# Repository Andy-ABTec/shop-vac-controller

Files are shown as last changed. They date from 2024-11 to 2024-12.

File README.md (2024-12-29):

# Shop Vac Controller

An Arduino Nano-based project to provide automatic control for a small workshop vacuum by either sensing tool use, or by a keyfob style remote control.

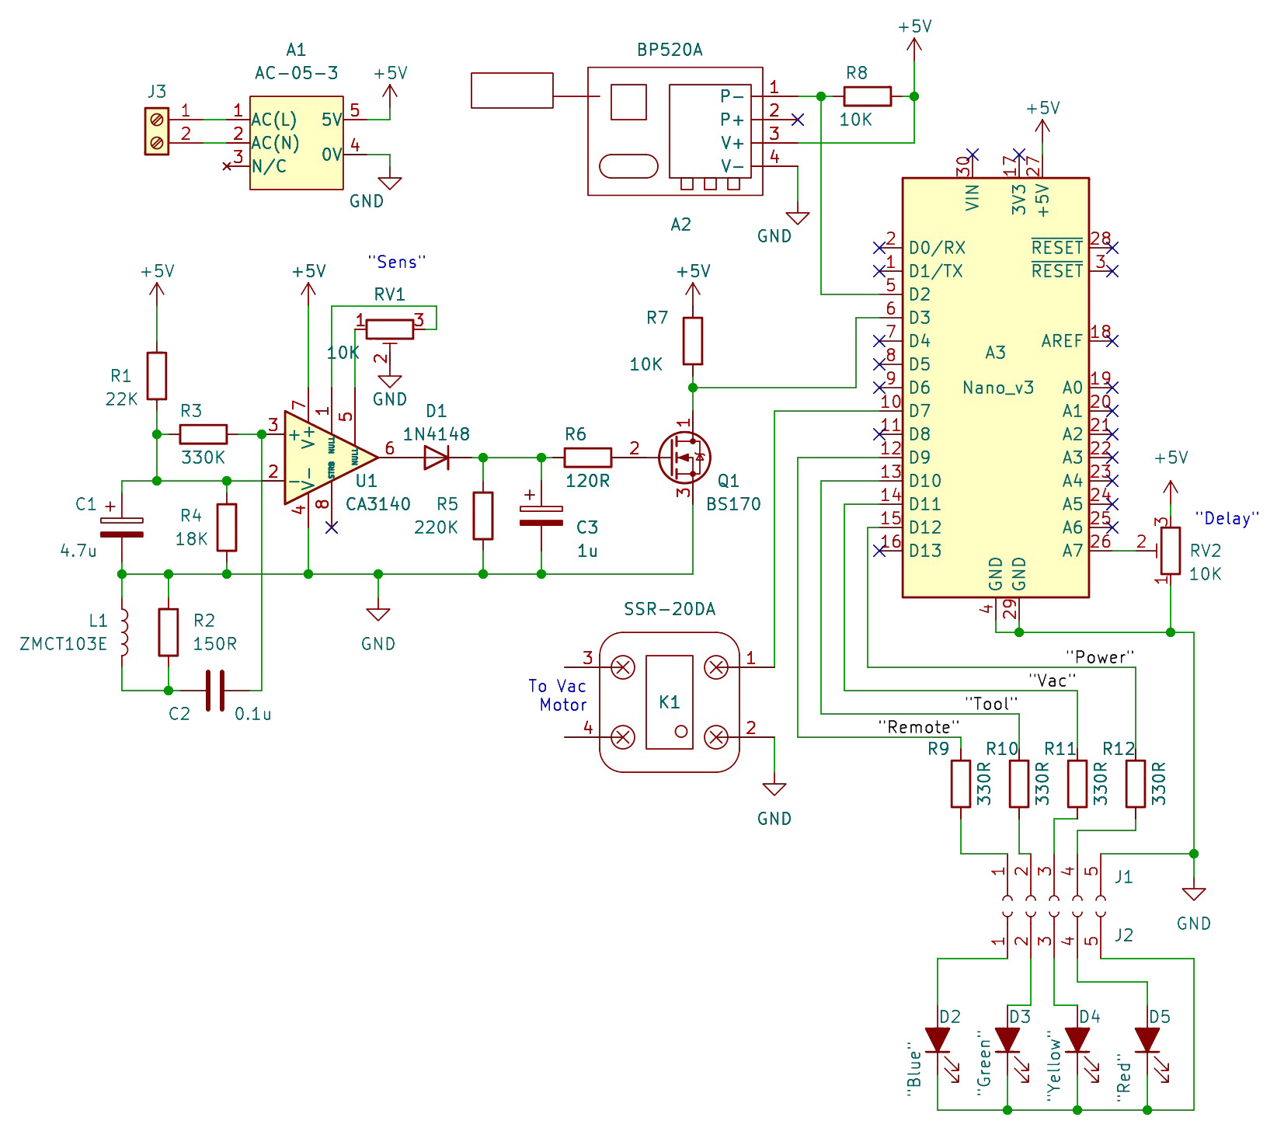
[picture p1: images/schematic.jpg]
schematic


Four LEDs display the status of the controller and its trigger source. It should be noted that the "Vac On" LED flashes if a startup or shutdown delay is in progress.

 Power control for the vacuum is provided by a 20A solid state relay and the remote control by a small keyfob and receiver ( I used a [**fob/receiver** from Amazon](https://www.amazon.co.uk/gp/product/B08SHQ749R/)).

Power-tool on/off sensing is provided by a small circuit by [**0033mer**](https://www.youtube.com/user/0033mer) using a cheap current transformer  I found on [**YouTube**](https://www.youtube.com/watch?v=gvBVxQGS_OU&t=280s).

Both the *sensitivity* of the current sensor and the turn-off delay for the vacuum control relay are adjustable by preset potentiometers.

Whilst the remote has no turn-on delay, the vacuum turns on 3s after the power tool is started (this setting may be adjusted in the Arduino code). This delay helps to reduce the excessive surge current created if both the power tool and the vacuum are turned on together.

The turn-off delay is the same for both the power tool and the remote fob, and can easily be adjusted between 3s and 30s with a preset potentiometer, this allows time for the wood chips and sawdust to be cleared from the vacuum hose.

It should be noted that if the vacuum is initiated by the mains-powered tool turning on, it can only be turned off by stopping the tool, and, in a similar way, if initiated by the remote fob it can only be turned off by the remote fob.

The vacuum power circuit should include a suitable fuse.

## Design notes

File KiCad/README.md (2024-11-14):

# Shop Vac Controller

A small Arduino Nano-based project to provide automatic control for a workshop vacuum by either sensing tool use, or by a keyfob style remote control.
<p align="center"><br>
<br>
<span style="font-size:3;font-style: italic">Circuit Diagram</span></p>Four LEDs display the status of the controller and its trigger source. It should be noted that the "Vac On" LED flashes if a startup or shutdown delay is in progress.

<p align="center"><br>

<br>
<span style="font-size:3;font-style:italic">Power Connections</span></p>

 Power control for the vacuum is provided by a 20A solid state relay and the remote control by a small keyfob and receiver ( I used a [**fob receiver** from Amazon](https://www.amazon.co.uk/gp/product/B08SHQ749R/).

Power-tool on/off sensing is provided by a small circuit by [**0033mer**](https://www.youtube.com/user/0033mer) using a cheap current transformer  I found on [**YouTube**](https://www.youtube.com/watch?v=gvBVxQGS_OU&t=280s).

Both the *sensitivity* of the current sensor and the turn-off delay for the vacuum control relay are adjustable by preset potentiometers.

Whilst the remote has no turn-on delay, the vacuum turns on 3s after the power tool is started (this setting may be adjusted in the Arduino code). This delay helps to reduce the excessive surge current created if both the power tool and the vacuum are turned on together.

The turn-off delay is the same for both the power tool and the remote fob, and can easily be adjusted between 3s and 30s with a preset potentiometer, this allows time for the wood chips and sawdust to be cleared from the vacuum hose.

It should be noted that if the vacuum is initiated by the mains-powered tool turning on it can only be turned off by stopping the tool and, in a similar way, if initiated by the remote fob it can only be turned off by the remote fob.

The vacuum power circuit should include a suitable fuse.

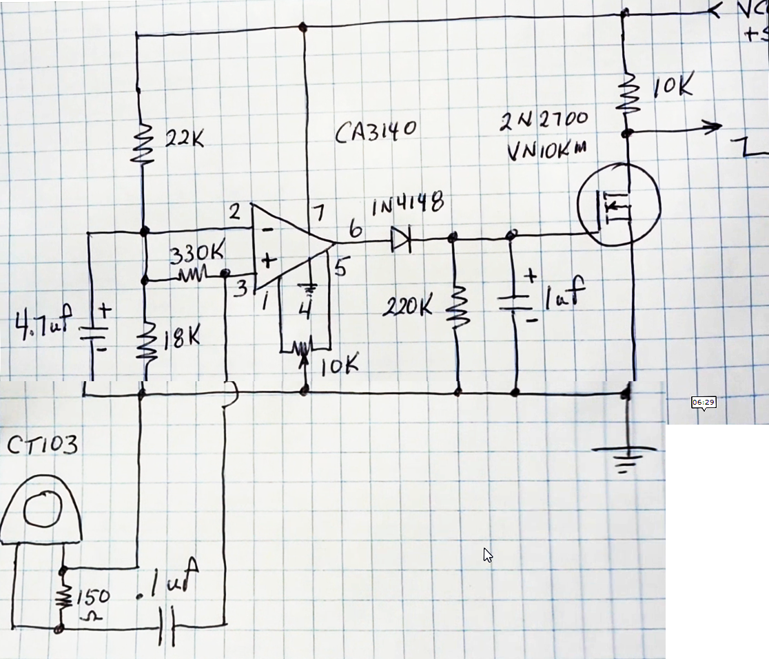
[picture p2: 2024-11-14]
KiCad/AC Current Detection Interface.png

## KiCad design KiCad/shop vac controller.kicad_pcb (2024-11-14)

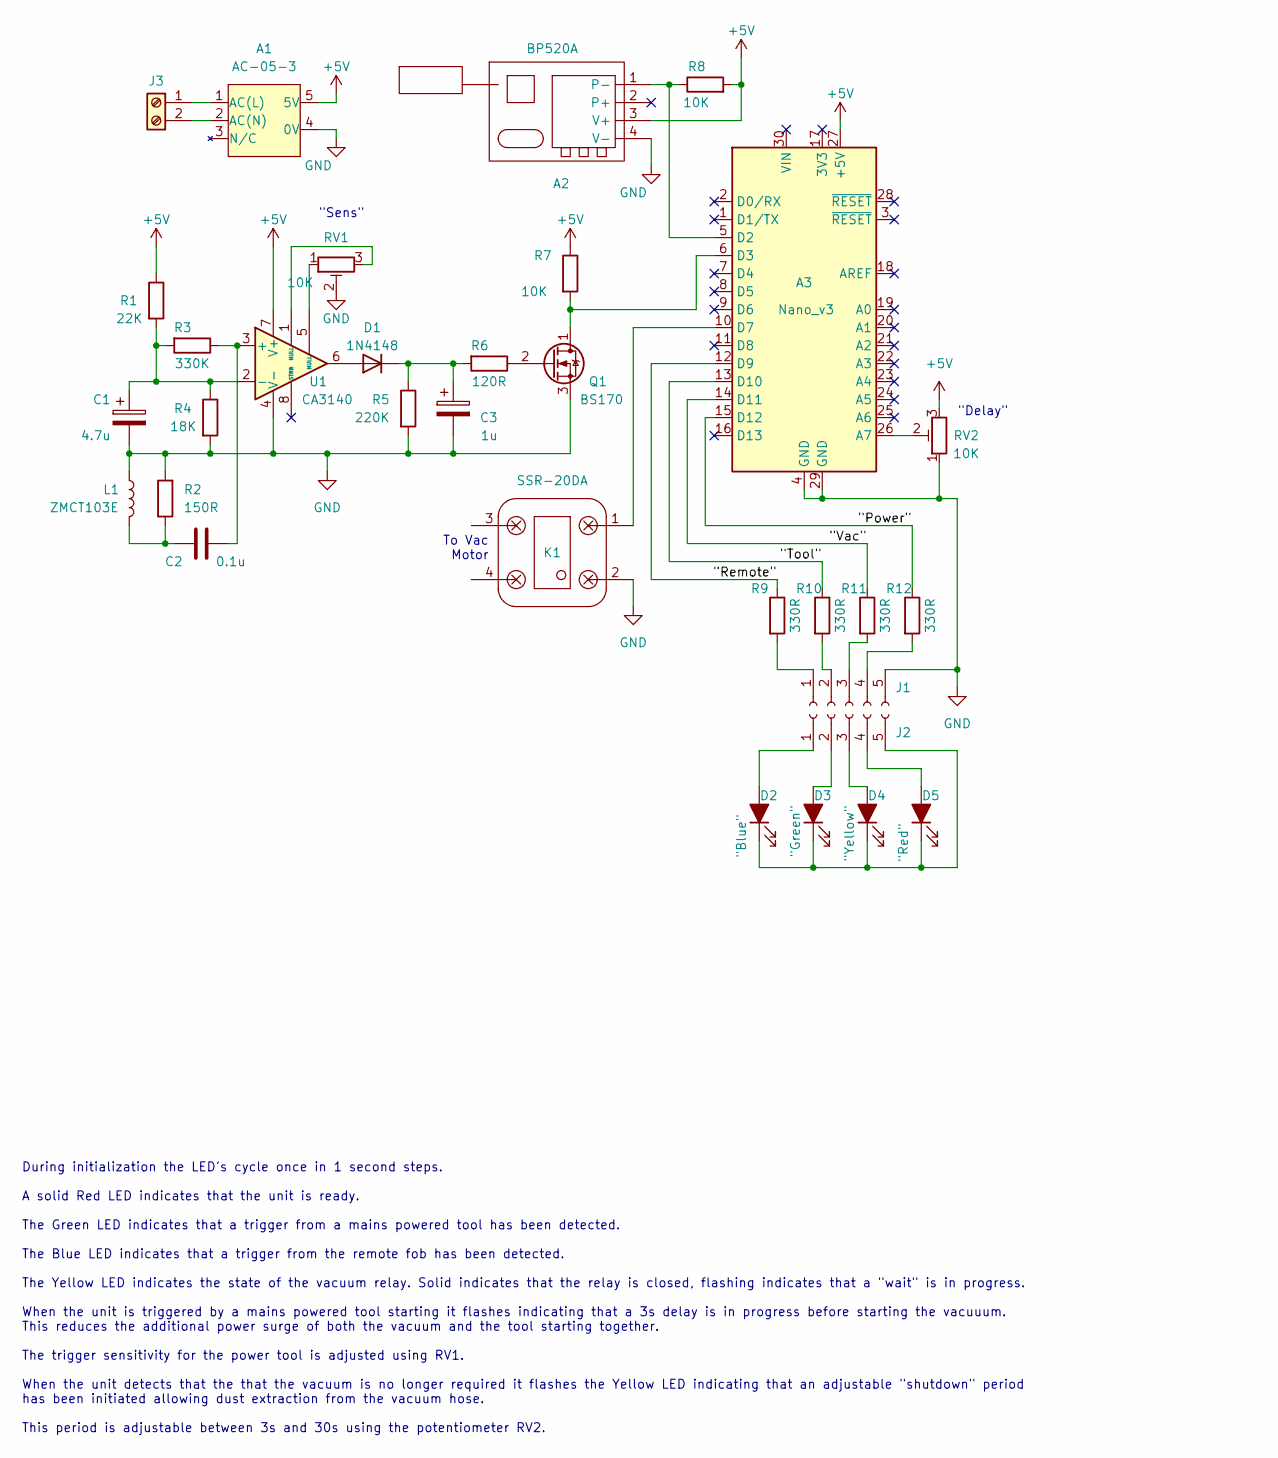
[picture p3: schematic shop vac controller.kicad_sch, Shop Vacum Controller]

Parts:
A1: AC-05-3
A2: BP520A
A3: Nano_v3; Arduino_Nano
C1: 4.7u; C_Radial_D5.0mm_H11.0mm_P2.00mm
C2: 0.1u; C_Disc_D5.1mm_W3.2mm_P5.00mm
C3: 1u; C_Radial_D4.0mm_H7.0mm_P1.50mm
D1: 1N4148; D_DO-35_SOD27_P7.62mm_Horizontal
D2: "Blue"; LED_D3.0mm
D3: "Green"; LED_D3.0mm
D4: "Yellow"; LED_D3.0mm
D5: "Red"; LED_D3.0mm
J1, J2: Conn_01x05_Socket; 5 pin jumper
J3: Screw_Terminal_01x02; TerminalBlock_bornier-2_P5.08mm
K1: SSR-20DA; TerminalBlock_bornier-2_P5.08mm
L1: ZMCT103E
Q1: BS170; TO-92_Inline
R1: 22K; R_Axial_DIN0204_L3.6mm_D1.6mm_P7.62mm_Horizontal
R2: 150R; R_Axial_DIN0204_L3.6mm_D1.6mm_P7.62mm_Horizontal
R3: 330K; R_Axial_DIN0204_L3.6mm_D1.6mm_P7.62mm_Horizontal
R4: 18K; R_Axial_DIN0204_L3.6mm_D1.6mm_P7.62mm_Horizontal
R5: 220K; R_Axial_DIN0204_L3.6mm_D1.6mm_P7.62mm_Horizontal
R6: 120R; R_Axial_DIN0204_L3.6mm_D1.6mm_P7.62mm_Horizontal
R7, R8: 10K; R_Axial_DIN0204_L3.6mm_D1.6mm_P7.62mm_Horizontal
R9, R10, R11, R12: 330R; R_Axial_DIN0204_L3.6mm_D1.6mm_P7.62mm_Horizontal
RV1, RV2: 10K; Potentiometer_Runtron_RM-065_Vertical
U1: CA3140; DIP-8_W7.62mm

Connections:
+5V: A1.5 (5V), A2.3 (V+), A3.27 (+5V), R1.1, R7.1, R8.2, RV2.3, U1.7 (V+)
/"Power": A3.15 (D12), R12.1
/"Remote": A3.12 (D9), R9.1
/"Tool": A3.13 (D10), R10.1
/"Vac": A3.14 (D11), R11.1
GND: A1.4 (0V), A2.4 (V-), A3.4 (GND), A3.29 (GND), C1.2, C3.2, J1.5, K1.2, L1.1, Q1.3 (S), R2.2, R4.2, R5.2, RV1.2, RV2.1, U1.4 (V-)
unnamed: A1.1 (AC(L)), J3.1
unnamed: A1.2 (AC(N)), J3.2
unnamed: A2.1 (P-), A3.5 (D2), R8.1
unnamed: A3.26 (A7), RV2.2
unnamed: A3.6 (D3), Q1.1 (D), R7.2
unnamed: A3.10 (D7), K1.1
unnamed: C2.1, L1.2, R2.1
unnamed: D1.2 (A), U1.6
unnamed: C3.1, D1.1 (K), R5.1, R6.2
unnamed: D2.2 (A), J2.1
unnamed: D2.1 (K), D3.1 (K), D4.1 (K), D5.1 (K), J2.5
unnamed: D3.2 (A), J2.2
unnamed: D4.2 (A), J2.3
unnamed: D5.2 (A), J2.4
unnamed: J1.1, R9.2
unnamed: J1.2, R10.2
unnamed: J1.3, R11.2
unnamed: J1.4, R12.2
unnamed: Q1.2 (G), R6.1
unnamed: RV1.1, U1.5 (NULL)
unnamed: RV1.3, U1.1 (NULL)
unnamed: C2.2, R3.1, U1.3 (+)
unnamed: C1.1, R1.2, R3.2, R4.1, U1.2 (-)

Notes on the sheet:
During initialization the LED's cycle once in 1 second steps. A solid Red LED indicates that the unit is ready. The Green LED indicates that a trigger from a mains powered tool has been detected. The Blue LED indicates that a trigger from the remote fob has been detected. The Yellow LED indicates t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
To Vac Motor
"Delay"
"Sens"

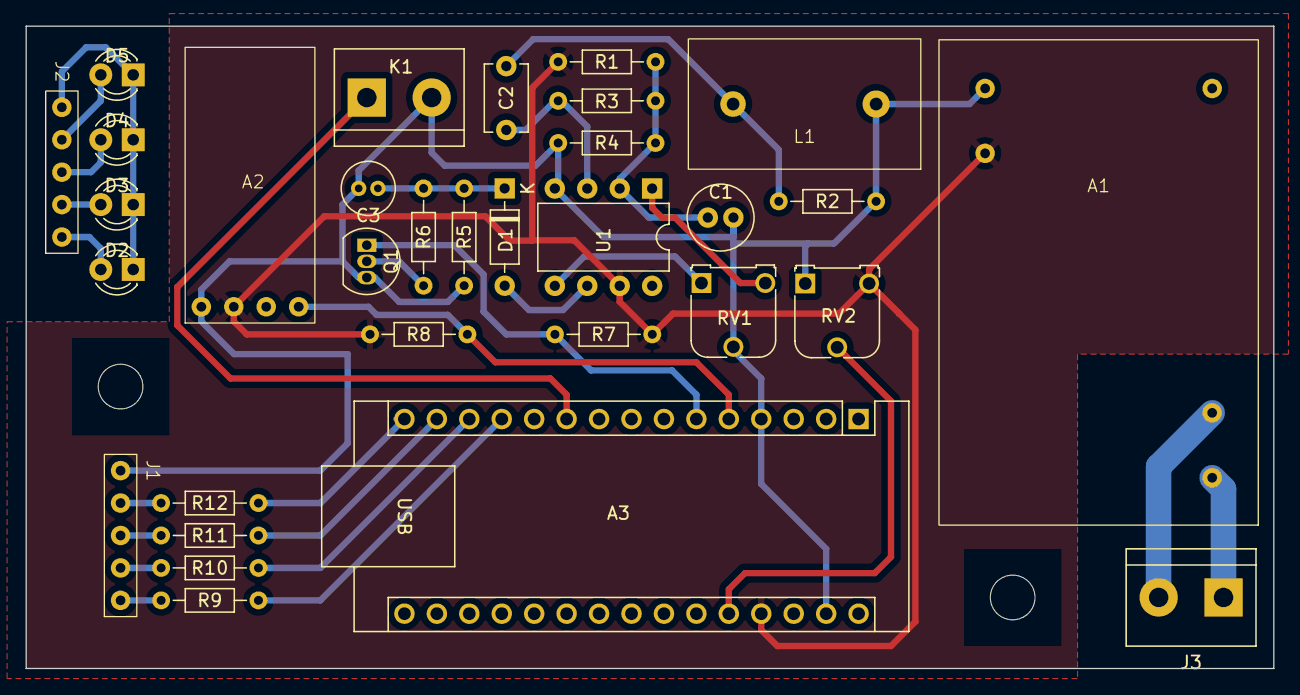
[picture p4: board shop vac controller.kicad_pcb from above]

Board: 2 copper layers, 97.7 x 50.3 mm, 32 parts (0 on the bottom side), 29 nets.

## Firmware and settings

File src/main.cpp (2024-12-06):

/*
   Arduino based Shop Vacuum Controller
   ====================================

   Created by: Andy B
   Version:    1.4
   Date:       30/03/2024
   License:    GNU 3.0

   Built and tested using VSCode/Platform IO on an Elegoo Nano, this project
   uses a current transformer to detect if a wired power tool has been started
   or detects if a remote control keyfob has been pressed to control a shop vac 
   using a solid state relay.
*/

// Include Libaries...
#include <Arduino.h>
#include <LibPrintf.h>

//Debug Control...
#define DEBUG 0                                     // #define DEBUG 0 -> Debug off,
                                                    // #define DEBUG 1 -> Debug on

// Initialize delay times...
#define onToolDelay 3                               // Delay between detecting the tool turning
                                                    // on and energising the vac relay
#define offDelayMin 3                               // Value sets the minimum off time delay
#define offDelayMax 30                              // Value sets the maximum off time delay
#define offDelayPin A7                              // pot connection to adjust the "off" time delay
#define vacLedFlashsPerSecond 4                     // Vacuum LED flash rate

// Define Pins...
#define remoteInt 2                                 // ISR trigger for remote
#define toolInt 3                                   // ISR trigger for tool
#define powerLed 12                                 // Red "Power" LED
#define vacLed 11                                   // Yellow "Vacuum" LED
#define toolLed 10                                  // Green "Tool" LED
#define remoteLed 9                                 // Blue "Remote" LED


#if DEBUG == 0
  #define relayPin 7                                // Relay o/p -> SSR via  jumper J2
#else
  #define relayPin 13                               // Relay o/p -> on-board test LED
#endif

// Define Flags...
bool remoteFlag=false;
bool toolFlag=false;
bool vacFlag=false;

// Calculate the off time delay based on the min and max delays and the pot setting
int offDelay(){
int x=analogRead(offDelayPin);
int offDelay=round((offDelayMax-offDelayMin)/1032.0*x+offDelayMin);
return(offDelay);
}

// Flash the vacuum led...
  void flash(int flashesPerSecond, int seconds){
  int rate=500/flashesPerSecond;
  for(int i=0; i<flashesPerSecond*seconds*2; i++)
  {
    digitalWrite(vacLed,not(digitalRead(vacLed)));
    delay(rate);
  }
}

// Remote Interrupt Service Routines...
void remoteISR(void){
  remoteFlag=not(digitalRead(remoteInt));
  #if DEBUG==1
    printf("remoteISR sets remoteFlag = %d\n",remoteFlag);
  #endif
}

void toolISR(void){
  toolFlag=not(digitalRead(toolInt));
  #if DEBUG==1
    printf("toolISR sets toolFlag = %d\n",toolFlag);
  #endif
}

// Setup...
void setup()
{
  #if DEBUG==1                                      // DEBUG: set up the serial port
    Serial.begin(9600);
  #endif

  // Initialise LED pins and blink LEDs...
  int led[4]={powerLed, vacLed, toolLed, remoteLed};
  for (int pin=0; pin<4; pin++)
  {
    pinMode(led[pin],OUTPUT);
    digitalWrite(led[pin],HIGH);
    delay(1000);
    digitalWrite(led[pin],LOW);
  }

  // Initialize relay pin...
  digitalWrite(relayPin,LOW);
  pinMode(relayPin,OUTPUT);

  #if DEBUG==1                                      // DEBUG: test the relay
    digitalWrite(relayPin,HIGH);
    delay(1000);
    digitalWrite(relayPin,LOW);
  #endif

  #if DEBUG==1                                      // DEBUG: print the offDelay
    printf("offDelay = %d\n",offDelay());
  #endif

// Attach interrupts...
attachInterrupt(digitalPinToInterrupt(remoteInt), remoteISR, CHANGE);
attachInterrupt(digitalPinToInterrupt(toolInt), toolISR, CHANGE);

// Setup complete, turn on the power led...
  digitalWrite(powerLed,HIGH);
}

// Loop...
void loop(){

  // Remote Start...
  if(remoteFlag==true && toolFlag==false && vacFlag==false){
    digitalWrite(remoteLed,true);                   // Turn on the Remote LED
    digitalWrite(vacLed,true);                      // Turn on the Vacuum LED
    digitalWrite(relayPin,true);                    // Turn on the relay
    vacFlag=true;
  }

  // Tool Start...
 if(remoteFlag==false && toolFlag==true && vacFlag==false){
    digitalWrite(toolLed,true);                     // Turn on the Remote
    flash(vacLedFlashsPerSecond,onToolDelay);       // flash the Vacuum LED
    digitalWrite(vacLed,true);                      // Turn on the Vacuum LED
    digitalWrite(relayPin,true);                    // Turn on the relay
    vacFlag=true;
  }

  // Stop...
  if(remoteFlag==false && toolFlag==false && vacFlag==true){
    flash(vacLedFlashsPerSecond,offDelay());        // flash the Vacuum LED
    digitalWrite(vacLed,false);                     // Make sure the Vacuum LED if off
    digitalWrite(relayPin,false);                   // Turn off the Vacuum relay
    vacFlag=false;
    digitalWrite(remoteLed,false);                  // Turn off the Remote LED
    digitalWrite(toolLed,false);                    // Turn off the Tool LED
  }
}

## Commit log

2022-05-21 Create Schematic_Shop Vac Controller_V1.3.png
2022-06-01 Updated Schematic
2022-06-01 updated link to schematic for v1.4
2022-06-08 update lint and PrintF
2022-12-17 spelling and syntax fixes
    [main.cpp]
2023-09-14 Update main.cpp
    test led for relay
2024-01-18 circuit update
    circuit update
2024-11-14 KiCAD include
    Include the live KiCAD files?
    [shop vac controller.kicad_pcb, shop vac controller.kicad_sch]
2024-11-14 KiCAD update
    [shop vac controller.kicad_sch]
2024-11-23 ignore kicad backups
2024-12-06 schematic text update
    [shop vac controller.kicad_sch]
2024-12-28 Update README.md
    Added schematic image
